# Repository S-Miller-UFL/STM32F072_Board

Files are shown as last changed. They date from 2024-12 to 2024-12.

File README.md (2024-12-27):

This is an STM32F072RBT6 based mcu board.

It contains the following features:
1. An ARM based STM32 microcontroller
2. An FT230 USB to UART transmitter that allows communication between the host computer and the MCU
3. A fully dedicated debug port. Labelled SWD.
4. 4 16 pin ports that are dedicated for communication with other boards. Such as SRAM, or FPGA's.

This design was made using KICAD. It's fully laid out, routed, and ready to be sent off for manufacturing.

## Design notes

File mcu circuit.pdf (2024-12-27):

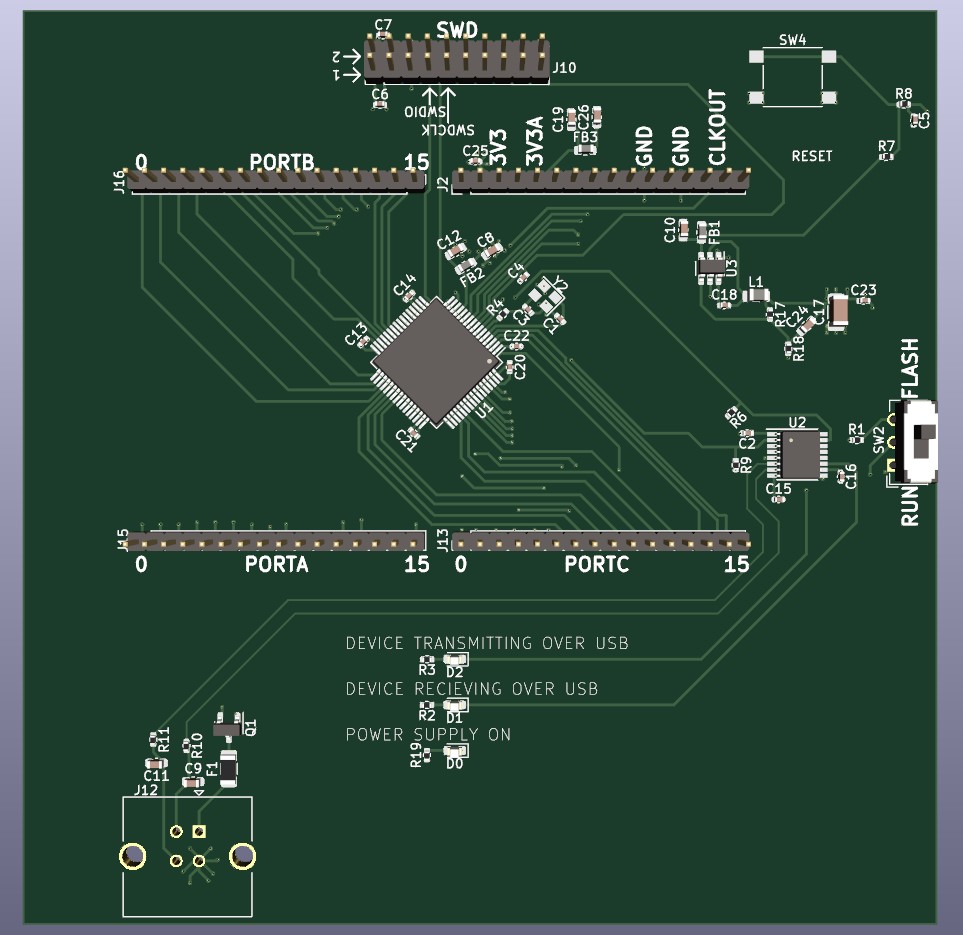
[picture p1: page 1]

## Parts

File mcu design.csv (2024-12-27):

Source: | C:\Program Files\KiCad\Projects\mcu design\mcu design\mcu design.kicad_sch
Date: | 8/18/2023 10:28:20 PM
Tool: | Eeschema 7.0.6
Generator: | C:\Program Files\KiCad\7.0\bin\scripting\plugins/bom_csv_grouped_by_value_with_fp.py
Component Count: | 60
Ref | Qnty | Value | Cmp name | Footprint | Description | Vendor | DNP
C1, C3 | 2 | 10pF | C | Capacitor_SMD:C_0402_1005Metric | Unpolarized capacitor
C2, C4, C6, C7, C13, C14, C15, C16, C20, C21, C22 | 11 | 0u1F | C | Capacitor_SMD:C_0402_1005Metric | Unpolarized capacitor
C5, C18 | 2 | 100nF | C | Capacitor_SMD:C_0402_1005Metric | Unpolarized capacitor
C8, C10, C12, C19, C26 | 5 | 10uF | C | Capacitor_SMD:C_0603_1608Metric | Unpolarized capacitor
C9, C11 | 2 | 47pF | C | Capacitor_SMD:C_0603_1608Metric | Unpolarized capacitor
C17 | 1 | 22uF | C | Capacitor_SMD:C_1206_3216Metric | Unpolarized capacitor
C23 | 1 | 1uF | C | Capacitor_SMD:C_0402_1005Metric | Unpolarized capacitor
C24 | 1 | 22pF | C | Capacitor_SMD:C_0603_1608Metric | Unpolarized capacitor
C25 | 1 | 22uF | C | Capacitor_SMD:C_0402_1005Metric | Unpolarized capacitor
D0, D1, D2 | 3 | LED | LED | Capacitor_SMD:C_0603_1608Metric | Light emitting diode
F1 | 1 | 500mA | Polyfuse | Fuse:Fuse_1206_3216Metric | Resettable fuse, polymeric positive temperature coefficient
FB1, FB2, FB3 | 3 | 2k Ohms at 100MHz | FerriteBead | Capacitor_SMD:C_0603_1608Metric | Ferrite bead
J2 | 1 | EXTERNAL_POWER/CONNECTOR | Conn_01x16_Pin | Connector_PinHeader_2.00mm:PinHeader_1x16_P2.00mm_Vertical | Generic connector, single row, 01x16, script generated
J10 | 1 | SWD connector | Conn_02x10_Odd_Even | Connector_PinHeader_2.00mm:PinHeader_2x10_P2.00mm_Vertical | Generic connector, double row, 02x10, odd/even pin numbering scheme (row 1 odd numbers, row 2 even numbers), script generated (kicad-library-utils/schlib/autogen/connector/)
J11 | 1 | PORTE/CONNECTOR | Conn_01x16_Pin | Connector_PinHeader_2.00mm:PinHeader_1x16_P2.00mm_Vertical | Generic connector, single row, 01x16, script generated
J12 | 1 | USB_B | USB_B | Connector_USB:USB_B_Amphenol_MUSB-D511_Vertical_Rugged | USB Type B connector
J13 | 1 | PORTC/CONNECTOR | Conn_01x16_Pin | Connector_PinHeader_2.00mm:PinHeader_1x16_P2.00mm_Vertical | Generic connector, single row, 01x16, script generated
J15 | 1 | PORTA/CONNECTOR | Conn_01x16_Pin | Connector_PinHeader_2.00mm:PinHeader_1x16_P2.00mm_Vertical | Generic connector, single row, 01x16, script generated
J16 | 1 | PORTB/CONNECTOR | Conn_01x16_Pin | Connector_PinHeader_2.00mm:PinHeader_1x16_P2.00mm_Vertical | Generic connector, single row, 01x16, script generated
L1 | 1 | 4u7H | L | Inductor_SMD:L_0805_2012Metric | Inductor
Q1 | 1 | Si7141DP | Si2319CDS | Package_SO:TSOP-5_1.65x3.05mm_P0.95mm | -4.4A Id, -40V Vds, P-Channel MOSFET, SOT-23
R1 | 1 | 1k Ohms | R | Capacitor_SMD:C_0402_1005Metric | Resistor
R2, R3 | 2 | 270 Ohms | R | Capacitor_SMD:C_0402_1005Metric | Resistor
R6, R9 | 2 | 2K2 Ohms | R | Capacitor_SMD:C_0402_1005Metric | Resistor
R7, R19 | 2 | 10k Ohms | R | Capacitor_SMD:C_0402_1005Metric | Resistor
R8 | 1 | 5k Ohms | R | Capacitor_SMD:C_0402_1005Metric | Resistor
R10, R11 | 2 | 27 Ohms | R | Capacitor_SMD:C_0402_1005Metric | Resistor
R17 | 1 | 40k2 Ohms | R | Capacitor_SMD:C_0402_1005Metric | Resistor
R18 | 1 | 13k Ohms | R | Capacitor_SMD:C_0402_1005Metric | Resistor
SW2 | 1 | ~ | SW_SPDT | Button_Switch_SMD:SW_SPDT_PCM12 | Switch, single pole double throw
SW4 | 1 | SW_Push | SW_Push | Button_Switch_THT:SW_PUSH-12mm | Push button switch, generic, two pins
U1 | 1 | STM32F072VBTx | STM32F072VBTx | Package_QFP:LQFP-100_14x14mm_P0.5mm | STMicroelectronics Arm Cortex-M0 MCU, 128KB flash, 16KB RAM, 48 MHz, 2.0-3.6V, 87 GPIO, LQFP100
U2 | 1 | FT230XQ | FT230XQ | Package_DFN_QFN:QFN-16-1EP_4x4mm_P0.65mm_EP2.1x2.1mm | Full Speed USB to Basic UART, QFN-16
U3 | 1 | DIO6970 | DIO6970 | Package_TO_SOT_SMD:SOT-23-6 | High-Efficiency 2A, 24V Input Synchronous Step Down Converter, SOT-23-6
Y2 | 1 | 32 MHz | Crystal | Crystal:Crystal_SMD_3225-4Pin_3.2x2.5mm | Two pin crystal

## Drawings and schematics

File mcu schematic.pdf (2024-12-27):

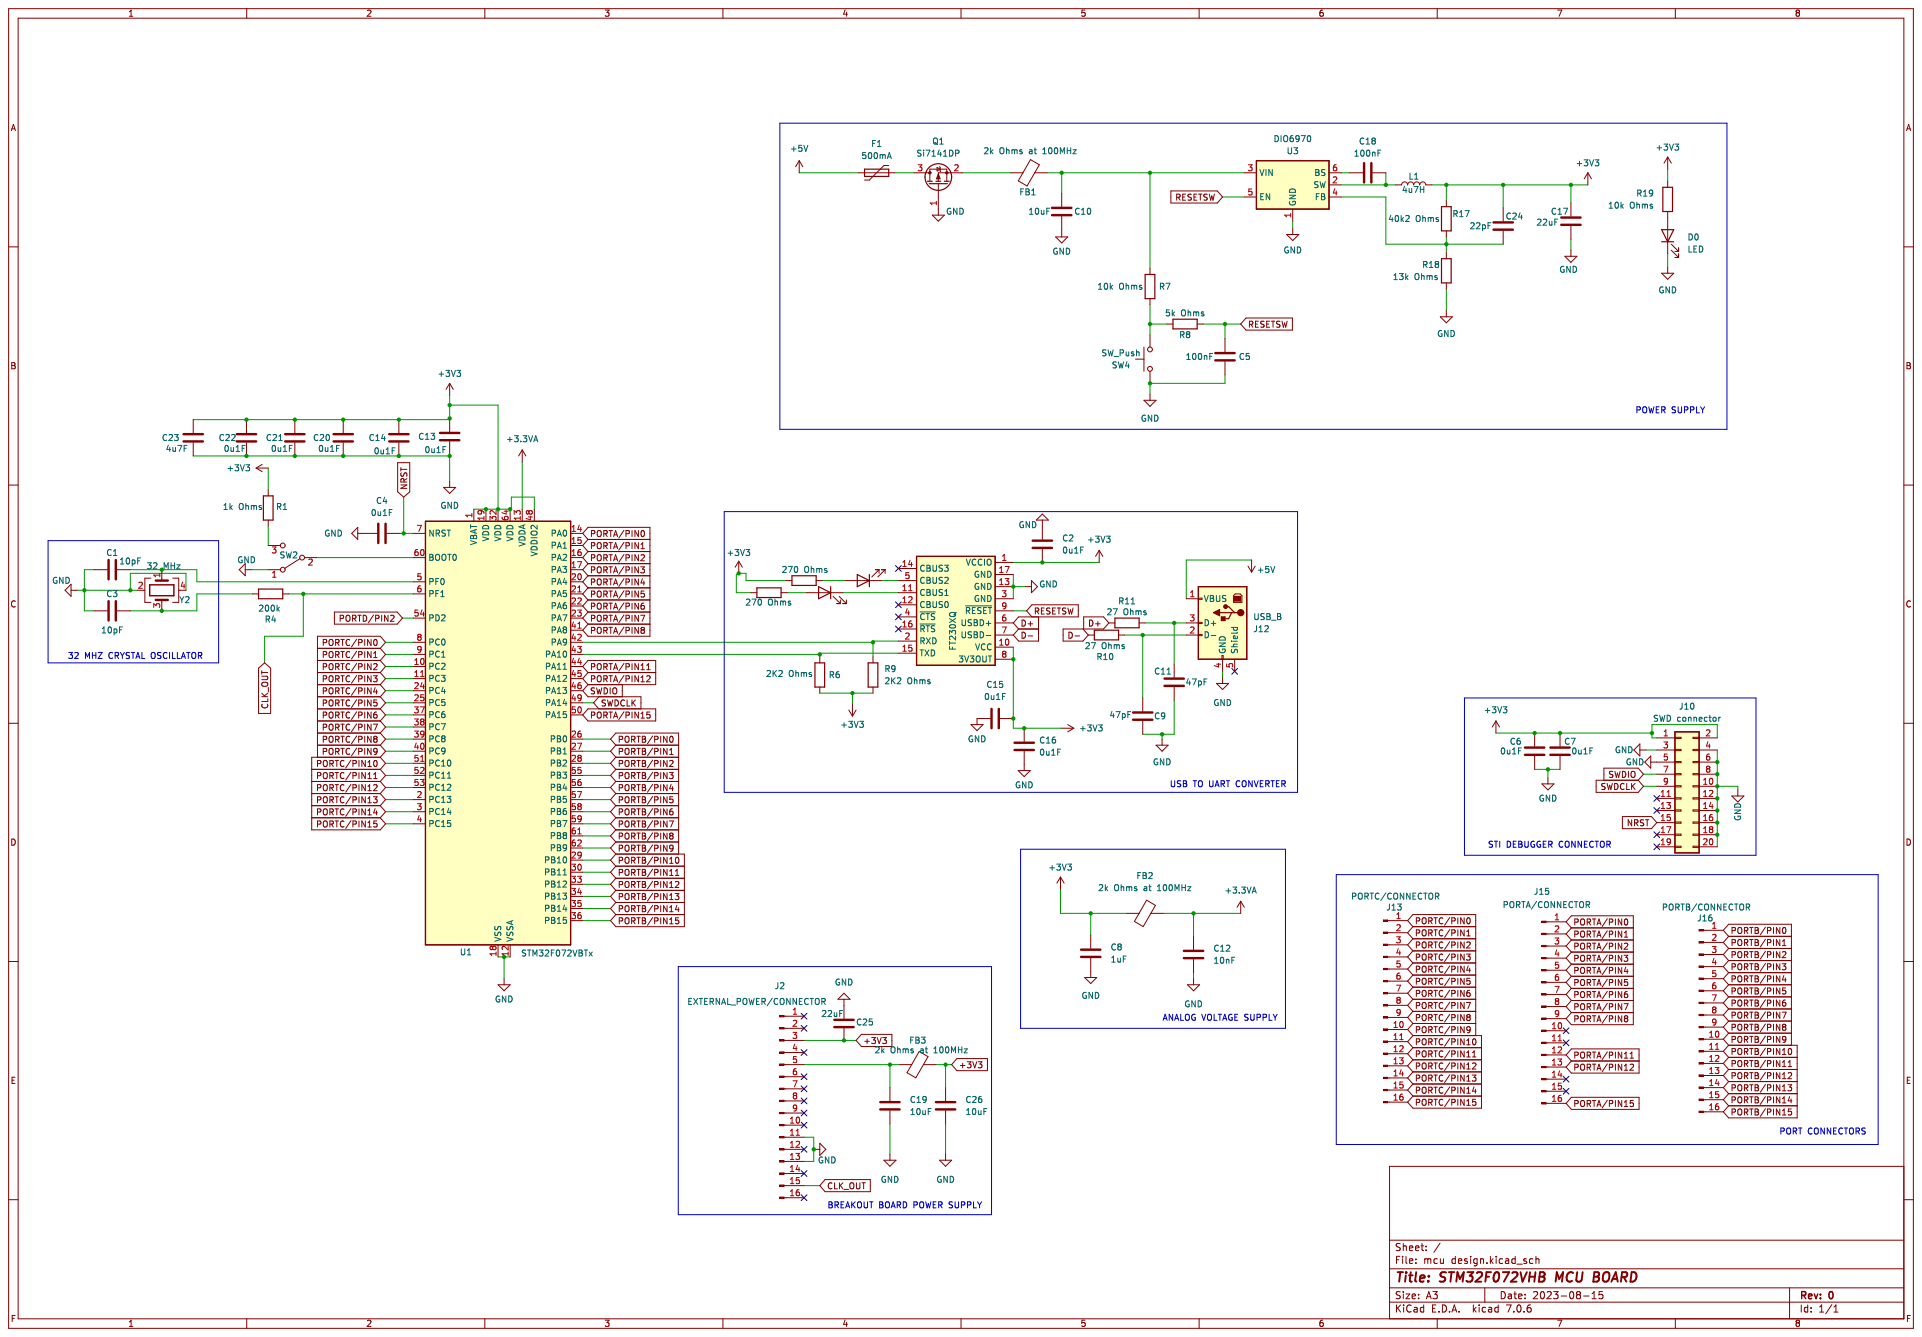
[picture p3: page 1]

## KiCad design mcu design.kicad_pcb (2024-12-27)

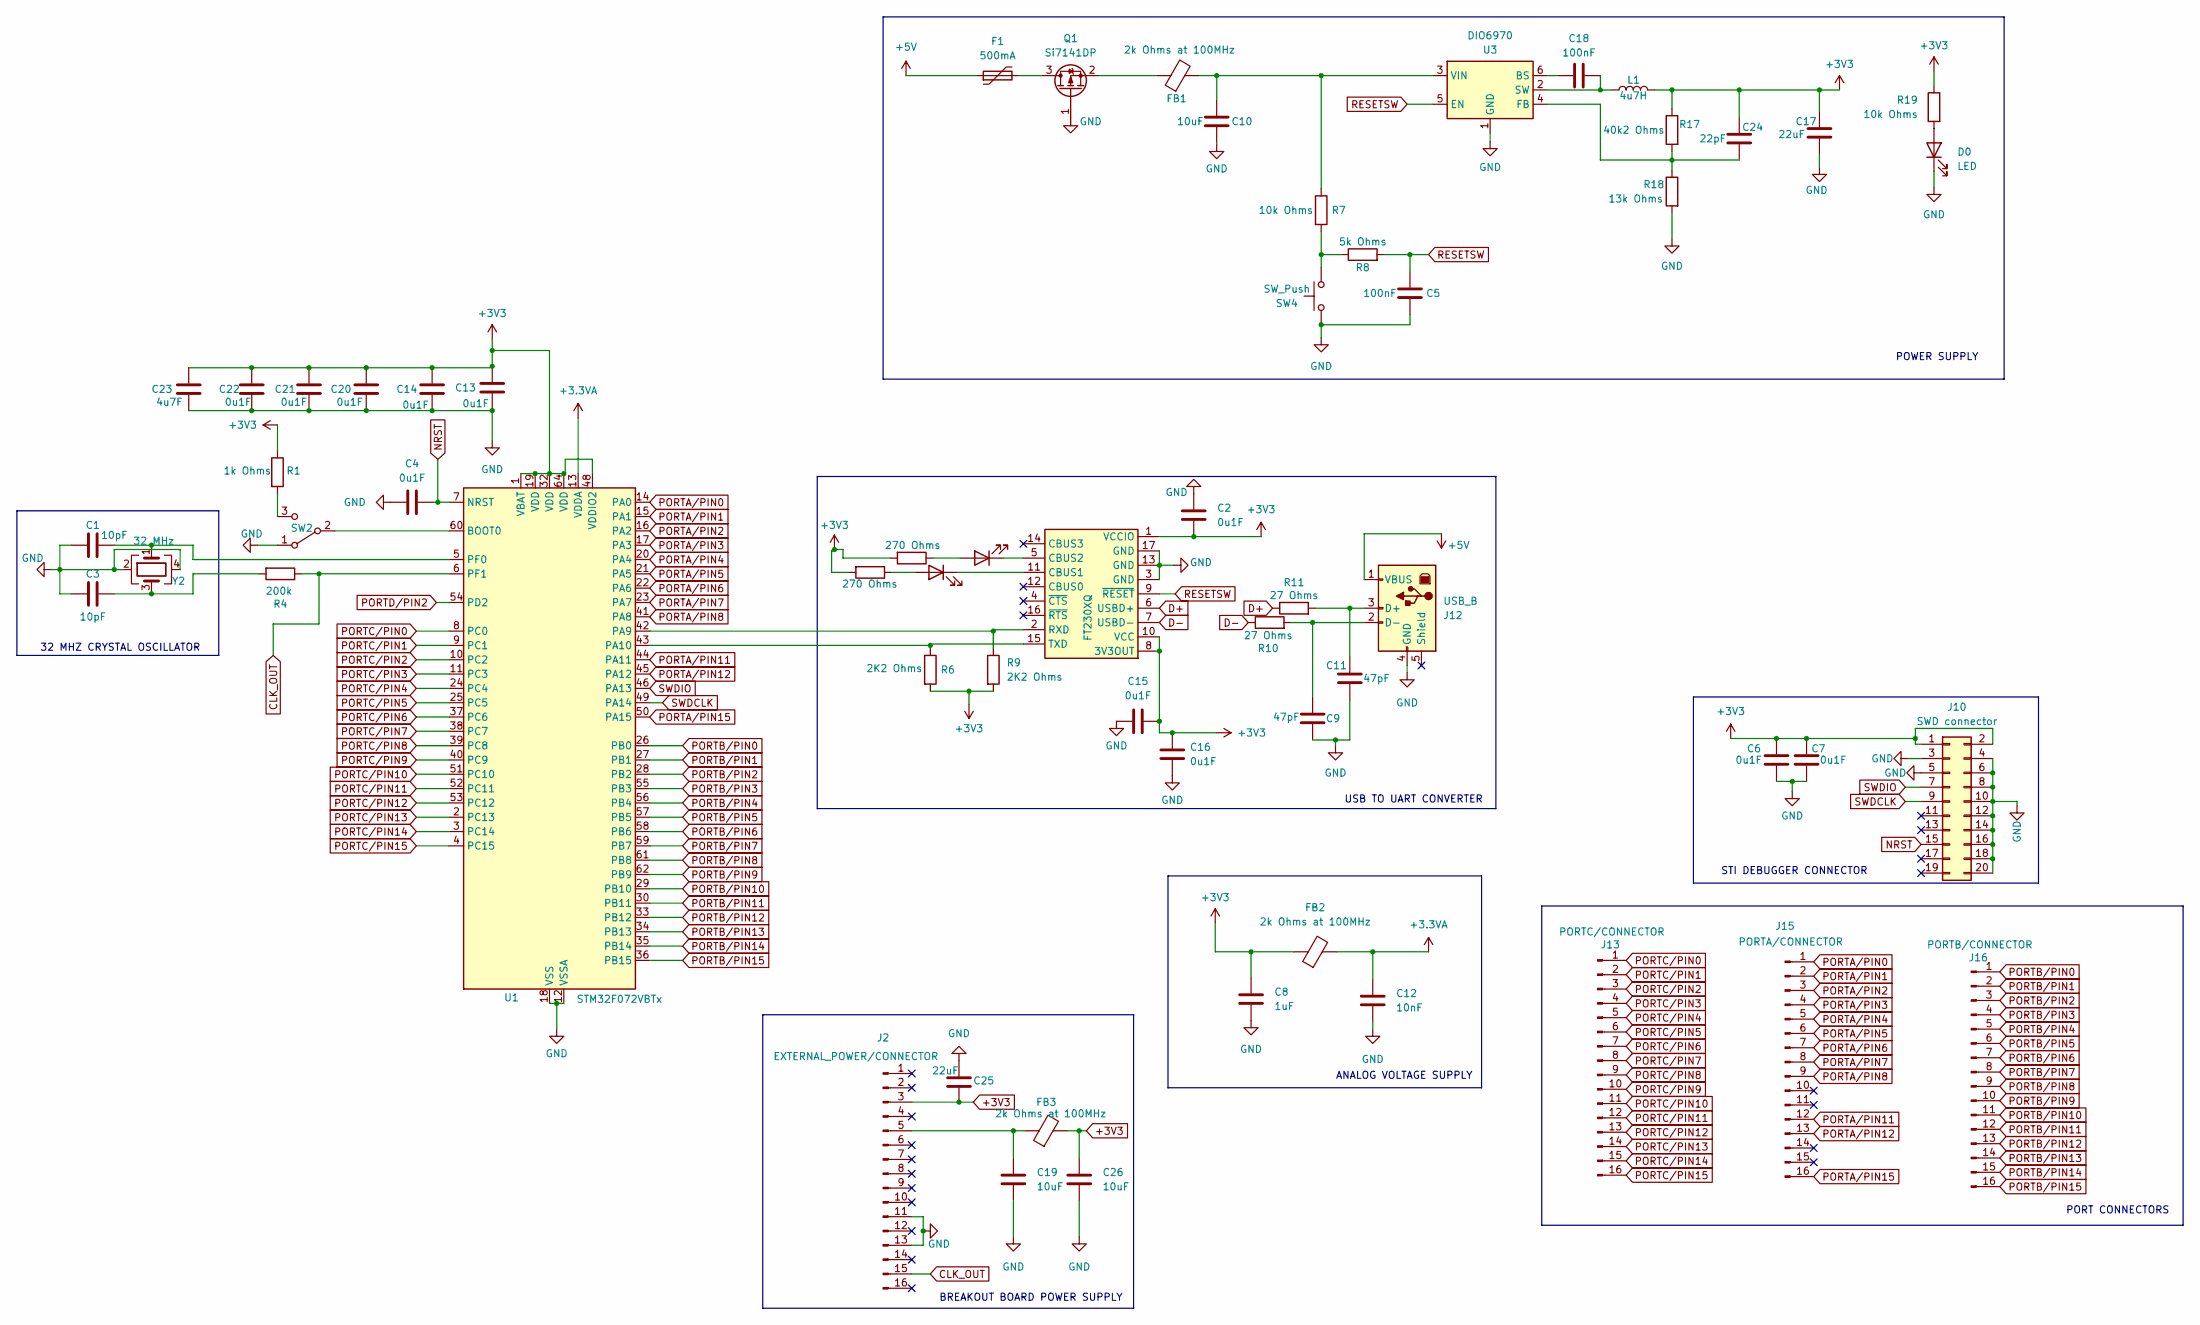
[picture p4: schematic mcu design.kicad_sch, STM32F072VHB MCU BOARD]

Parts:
C1, C3: 10pF; C_0402_1005Metric
C2, C4, C6, C7, C13, C14, C15, C16, C20, C21, C22: 0u1F; C_0402_1005Metric
C5, C18: 100nF; C_0402_1005Metric
C8: 1uF; C_0603_1608Metric
C9, C11: 47pF; C_0603_1608Metric
C10, C19, C26: 10uF; C_0603_1608Metric
C12: 10nF; C_0603_1608Metric
C17: 22uF; C_1206_3216Metric
C23: 4u7F; C_0402_1005Metric
C24: 22pF; C_0603_1608Metric
C25: 22uF; C_0402_1005Metric
D0, D1, D2: LED; LED_0603_1608Metric
F1: 500mA; Fuse_1206_3216Metric
FB1, FB2, FB3: 2k Ohms at 100MHz; L_0603_1608Metric
J2: EXTERNAL_POWER/CONNECTOR; PinHeader_1x16_P2.00mm_Vertical
J10: SWD connector; PinHeader_2x10_P2.00mm_Vertical
J12: USB_B; USB_B_Amphenol_MUSB-D511_Vertical_Rugged
J13: PORTC/CONNECTOR; PinHeader_1x16_P2.00mm_Vertical
J15: PORTA/CONNECTOR; PinHeader_1x16_P2.00mm_Vertical
J16: PORTB/CONNECTOR; PinHeader_1x16_P2.00mm_Vertical
L1: 4u7H; L_0805_2012Metric
Q1: Si7141DP; SOT-23
R1: 1k Ohms; R_0402_1005Metric
R2, R3: 270 Ohms; R_0402_1005Metric
R4: 200k; R_0402_1005Metric
R6, R9: 2K2 Ohms; R_0402_1005Metric
R7, R19: 10k Ohms; R_0402_1005Metric
R8: 5k Ohms; R_0402_1005Metric
R10, R11: 27 Ohms; R_0402_1005Metric
R17: 40k2 Ohms; R_0402_1005Metric
R18: 13k Ohms; R_0402_1005Metric
SW2: SW_CuK_JS202011CQN_DPDT_Straight
SW4: SW_Push; SW_Push_1P1T_NO_6x6mm_H9.5mm
U1: STM32F072VBTx; LQFP-64_10x10mm_P0.5mm
U2: FT230XQ; HTSSOP-16-1EP_4.4x5mm_P0.65mm_EP3.4x5mm
U3: DIO6970; SOT-23-6
Y2: 32 MHz; Crystal_SMD_2520-4Pin_2.5x2.0mm

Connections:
+3.3VA: C12.1, FB2.2, U1.13 (VDDA)
+3V3: C2.1, C6.1, C7.1, C8.1, C13.1, C14.1, C15.1, C16.1, C17.2, C20.1, C21.1, C22.1, C23.1, C24.2, C25.2, C26.1, FB2.1, FB3.2, J2.3, J10.1, J10.2, L1.2, R1.1, R2.2, R3.2, R6.2, R9.2, R17.1, R19.1, U1.1 (VBAT), U1.19 (VDD), U1.32 (VDD), U1.48 (VDDIO2), U1.64 (VDD), U2.1 (VCCIO), U2.8 (3V3OUT), U2.10 (VCC)
+5V: F1.1, J12.1 (VBUS)
CLK_OUT: J2.15, R4.1, U1.6 (PF1)
D+: R11.1, U2.6 (USBD+)
D-: R10.1, U2.7 (USBD-)
GND: C1.1, C2.2, C3.1, C4.1, C5.2, C6.2, C7.2, C8.2, C9.2, C10.2, C11.2, C12.2, C13.2, C14.2, C15.2, C16.2, C17.1, C19.2, C20.2, C21.2, C22.2, C23.2, C25.1, C26.2, D0.1 (K), J2.11, J2.13, J10.3, J10.4, J10.5, J10.6, J10.8, J10.10, J10.12, J10.14, J10.16, J10.18, J10.20, J12.4 (GND), Q1.1 (G), R18.2, SW2.1 (A), SW4.2, U1.12 (VSSA), U1.18 (VSS), U1.31 (VSS), U1.47 (VSS), U1.63 (VSS), U2.3 (GND), U2.13 (GND), U2.17 (GND), U3.1 (GND), Y2.2, Y2.4
NRST: C4.2, J10.15, U1.7 (NRST)
unnamed: C3.2, R4.2, Y2.3
unnamed: D0.2 (A), R19.2
unnamed: D1.2 (A), R2.1
unnamed: D1.1 (K), U2.11 (CBUS1)
unnamed: D2.2 (A), R3.1
unnamed: D2.1 (K), U2.5 (CBUS2)
unnamed: C19.1, FB3.1, J2.5
unnamed: C11.1, J12.3 (D+), R11.2
unnamed: C9.1, J12.2 (D-), R10.2
unnamed: F1.2, Q1.3 (D)
unnamed: FB1.1, Q1.2 (S)
unnamed: R7.2, R8.1, SW4.1
unnamed: SW2.2 (B), U1.60 (BOOT0)
unnamed: R1.2, SW2.3 (C)
unnamed: R9.1, U1.42 (PA9), U2.2 (RXD)
unnamed: R6.1, U1.43 (PA10), U2.15 (TXD)
unnamed: C1.2, U1.5 (PF0), Y2.1
unnamed: C18.1, U3.6 (BS)
unnamed: C24.1, R17.2, R18.1, U3.4 (FB)
unnamed: C18.2, L1.1, U3.2 (SW)
unnamed: C10.1, FB1.2, R7.1, U3.3 (VIN)
PORTA/PIN0: J15.1, U1.14 (PA0)
PORTA/PIN1: J15.2, U1.15 (PA1)
PORTA/PIN2: J15.3, U1.16 (PA2)
PORTA/PIN3: J15.4, U1.17 (PA3)
PORTA/PIN4: J15.5, U1.20 (PA4)
PORTA/PIN5: J15.6, U1.21 (PA5)
PORTA/PIN6: J15.7, U1.22 (PA6)
PORTA/PIN7: J15.8, U1.23 (PA7)
PORTA/PIN8: J15.9, U1.41 (PA8)
PORTA/PIN11: J15.12, U1.44 (PA11)
PORTA/PIN12: J15.13, U1.45 (PA12)
PORTA/PIN15: J15.16, U1.50 (PA15)
PORTB/PIN0: J16.1, U1.26 (PB0)
PORTB/PIN1: J16.2, U1.27 (PB1)
PORTB/PIN2: J16.3, U1.28 (PB2)
PORTB/PIN3: J16.4, U1.55 (PB3)
PORTB/PIN4: J16.5, U1.56 (PB4)
PORTB/PIN5: J16.6, U1.57 (PB5)
PORTB/PIN6: J16.7, U1.58 (PB6)
PORTB/PIN7: J16.8, U1.59 (PB7)
PORTB/PIN8: J16.9, U1.61 (PB8)
PORTB/PIN9: J16.10, U1.62 (PB9)
PORTB/PIN10: J16.11, U1.29 (PB10)
PORTB/PIN11: J16.12, U1.30 (PB11)
PORTB/PIN12: J16.13, U1.33 (PB12)
PORTB/PIN13: J16.14, U1.34 (PB13)
PORTB/PIN14: J16.15, U1.35 (PB14)
PORTB/PIN15: J16.16, U1.36 (PB15)
PORTC/PIN0: J13.1, U1.8 (PC0)
PORTC/PIN1: J13.2, U1.9 (PC1)
PORTC/PIN2: J13.3, U1.10 (PC2)
PORTC/PIN3: J13.4, U1.11 (PC3)
PORTC/PIN4: J13.5, U1.24 (PC4)
PORTC/PIN5: J13.6, U1.25 (PC5)
PORTC/PIN6: J13.7, U1.37 (PC6)
PORTC/PIN7: J13.8, U1.38 (PC7)
PORTC/PIN8: J13.9, U1.39 (PC8)
PORTC/PIN9: J13.10, U1.40 (PC9)
PORTC/PIN10: J13.11, U1.51 (PC10)
PORTC/PIN11: J13.12, U1.52 (PC11)
PORTC/PIN12: J13.13, U1.53 (PC12)
PORTC/PIN13: J13.14, U1.2 (PC13)
PORTC/PIN14: J13.15, U1.3 (PC14)
PORTC/PIN15: J13.16, U1.4 (PC15)
PORTD/PIN2: U1.54 (PD2)
RESETSW: C5.1, R8.2, U2.9 (~RESET), U3.5 (EN)
SWDCLK: J10.9, U1.49 (PA14)
SWDIO: J10.7, U1.46 (PA13)

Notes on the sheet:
POWER SUPPLY
32 MHZ CRYSTAL OSCILLATOR
PORT CONNECTORS
BREAKOUT BOARD POWER SUPPLY
USB TO UART CONVERTER
ANALOG VOLTAGE SUPPLY
STI DEBUGGER CONNECTOR

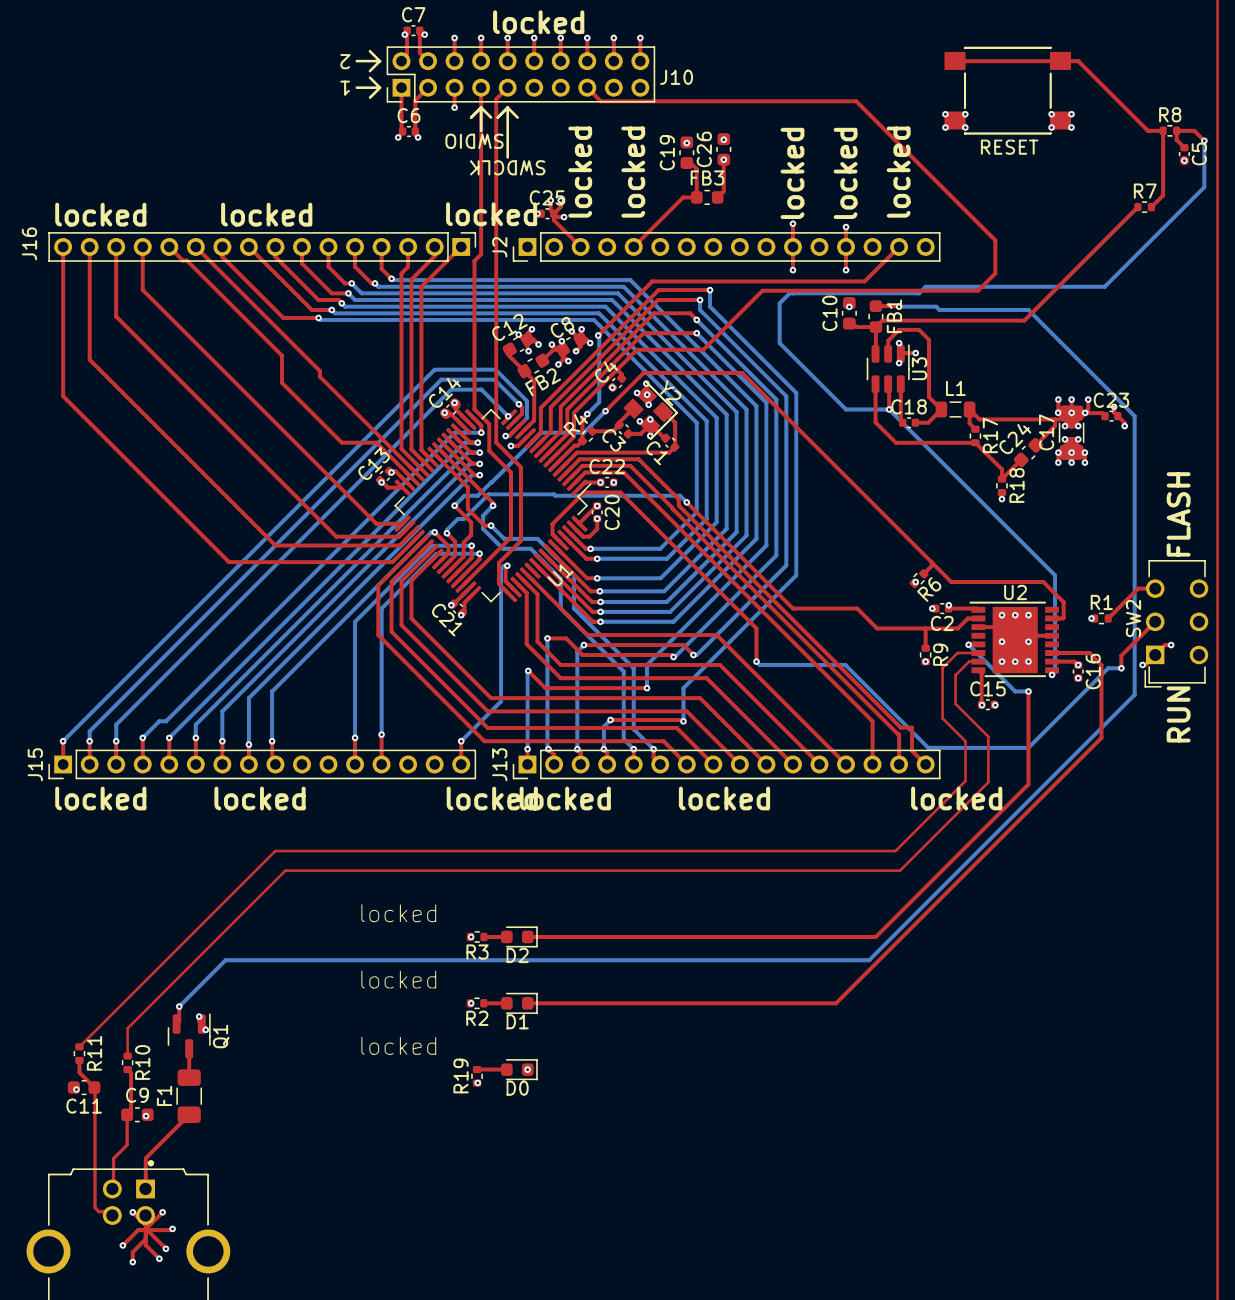
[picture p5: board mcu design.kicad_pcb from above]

Board: 4 copper layers, 59 parts (0 on the bottom side), 75 nets.
